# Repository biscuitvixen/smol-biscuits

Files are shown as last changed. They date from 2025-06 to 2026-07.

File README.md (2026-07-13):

# 🍪 Smol Biscuits SlimeVR Trackers






My own SlimeVR-compatible trackers, built because I wanted something
smaller. Like butterflies but before they were out! Custom PCB on a
Seeed Studio XIAO nRF52840, custom firmware fork, and a two-piece 3D
printed case with a flexible link between the battery and PCB sections.
They fit great and I love them!

## Table of Contents

- [Hardware](#hardware)
- [3D Printed Case](#3d-printed-case)
- [Firmware](#firmware)
- [Assembly](#assembly)
- [Setup & Calibration](#setup--calibration)

## Hardware

### PCB

Designed in KiCad, files in [`pcb/`](./pcb). A minimal carrier board for
the XIAO nRF52840, with sensors mounted on the opposite side.

### Sensors

| Component | Model | Function |
|---|---|---|
| IMU | ICM-45686 | 6-axis motion sensing |
| Magnetometer | QMC-6309 | Magnetic field detection |

### Battery

The board takes a LiPo. The included case is sized around a 150mAh cell -
go bigger if your case design has room for it.

## 3D Printed Case

Two-piece design: separate battery and PCB compartments connected by a
flexible TPU link. The joint lets the tracker bend naturally against your
body, which makes a real difference for all-day wear.

Print the flex link in TPU. Base plates should be PETG - they take real
strain from the strap and PLA will eventually fail on you. The top cover
and switch piece can be PLA or PETG, whichever you have to hand.

## Firmware

Firmware lives in [`firmware/`](./firmware) as a git submodule - a fork of
the SlimeVR firmware with specific support for this PCB.

Pre-compiled firmware is available in the [releases section](../../releases).

### Building from source

1. Clone with submodules:
   ```bash
   git clone --recurse-submodules https://github.com/biscuitvixen/smol-biscuits.git
   ```

2. Follow the [SlimeVR compilation guide](https://docs.slimevr.dev/smol-slimes/firmware/smol-compiling-firmware.html),
   then build with:
   ```bash
   west build -p auto -b xiao_ble -d build . -- -DNCS_TOOLCHAIN_VERSION=NONE -DBOARD_ROOT=.
   ```

## Assembly

### Soldering

The components on this board are small. Take your time.

1. Solder the sensor components onto the PCB. Leave the XIAO for now.
2. Pre-tin the battery terminals on the XIAO and the matching footprint
   on the PCB.
3. Use the solder jig to position the XIAO with battery terminals facing up.
4. Apply flux, place the sensor PCB on top aligning the battery terminals,
   and heat through the square pass-through pads while pressing the boards
   flat. Let it cool fully before moving it.
5. Inspect all joints and check for shorts with a multimeter before
   continuing.
6. Solder the castellated pins around the PCB edge, then solder the battery
   to the back of the sensor board.

### Programming

**Tracker:**

1. Connect via USB-C and double-tap the reset button. The device should
   appear as `XIAO-SENSE`.
2. Copy `update-slimenrf_xiao_sense_bootloader-0.9.2-SlimeVR.7_nosd.uf2`
   to the drive. It will remount as `SLIMENRF_XIAO_SENSE`.
3. Copy `firmware_tracker.uf2` to the drive. The tracker reboots
   automatically.

**Receiver:**

The Holyiot receiver is programmed via Nordic nRF Connect Programmer - flash
`firmware_receiver.hex`. For other hardware, follow the
[SlimeVR receiver docs](https://docs.slimevr.dev).

### Case assembly

1. Slide both bases onto a 30mm strap with the notches facing each other.
2. Place the flex link between the bases in its slot.
3. Insert the battery spacer, then lay the battery on top.
4. Hold the battery in place by its wires and snap the battery base down.
5. Place the PCB into the PCB base, aligning the switch with the cutout.
6. Slide the switch slider over the PCB switch.
7. Snap the top cover into place and adjust the strap to fit.

## Setup & Calibration

Follow the [SlimeVR pairing and calibration guide](https://docs.slimevr.dev/smol-slimes/firmware/smol-pairing-and-calibration.html).

## License

### Hardware

PCB files, 3D models, schematics, and case designs are licensed under
[CC BY-NC-SA 4.0](LICENSE-CC-BY-NC-SA). Personal and educational use is
free - just credit me and share improvements under the same terms.
Commercial use requires a separate arrangement; get in touch at
onlybiscuit7@gmail.com.

### Firmware

Firmware retains the original SlimeVR license terms:
[MIT](LICENSE-MIT) | [Apache 2.0](LICENSE-APACHE). See the firmware
submodule for the full details.

## Contributing

Pull requests and issues welcome.

## Support

- [SlimeVR Documentation](https://docs.slimevr.dev)
- SlimeVR Discord
- GitHub Issues

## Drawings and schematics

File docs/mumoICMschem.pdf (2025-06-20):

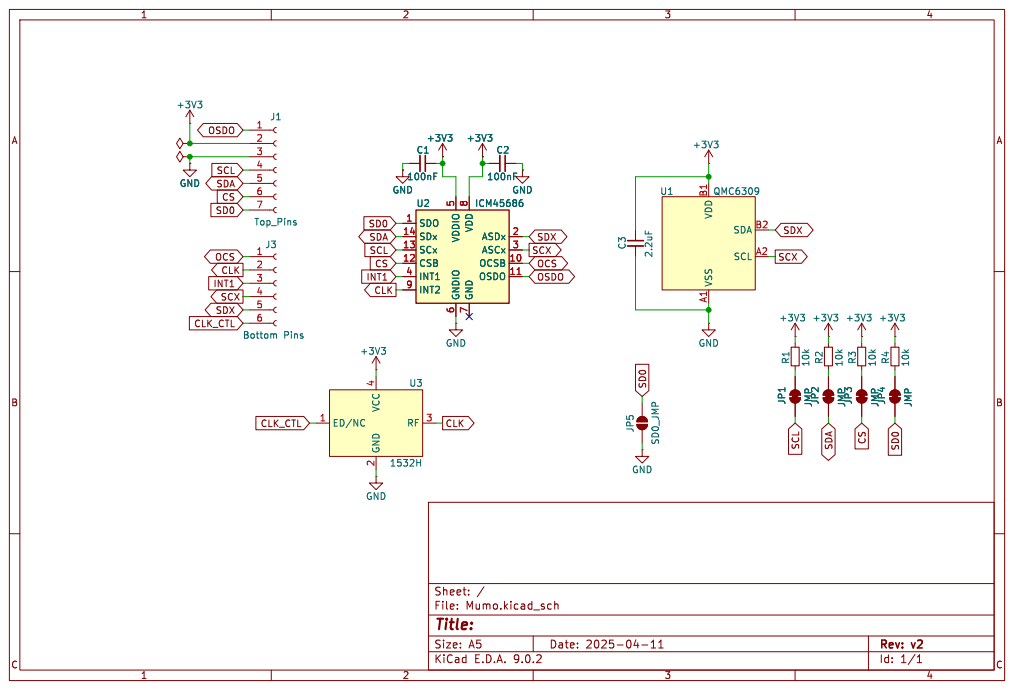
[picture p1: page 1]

7 ASDx 2 ASCx 3 OCSB 10 OSDO 11 U2 ICM45686 +3V3 GND VDD B1 VSS A1 SDA B2 SCL A2 U1 QMC6309 R3 10k +3V3 SCX CS

7 ASDx 2 ASCx 3 OCSB 10 OSDO 11 JP4 JP1 JMP JP2 JMP JP3 JMP JMP

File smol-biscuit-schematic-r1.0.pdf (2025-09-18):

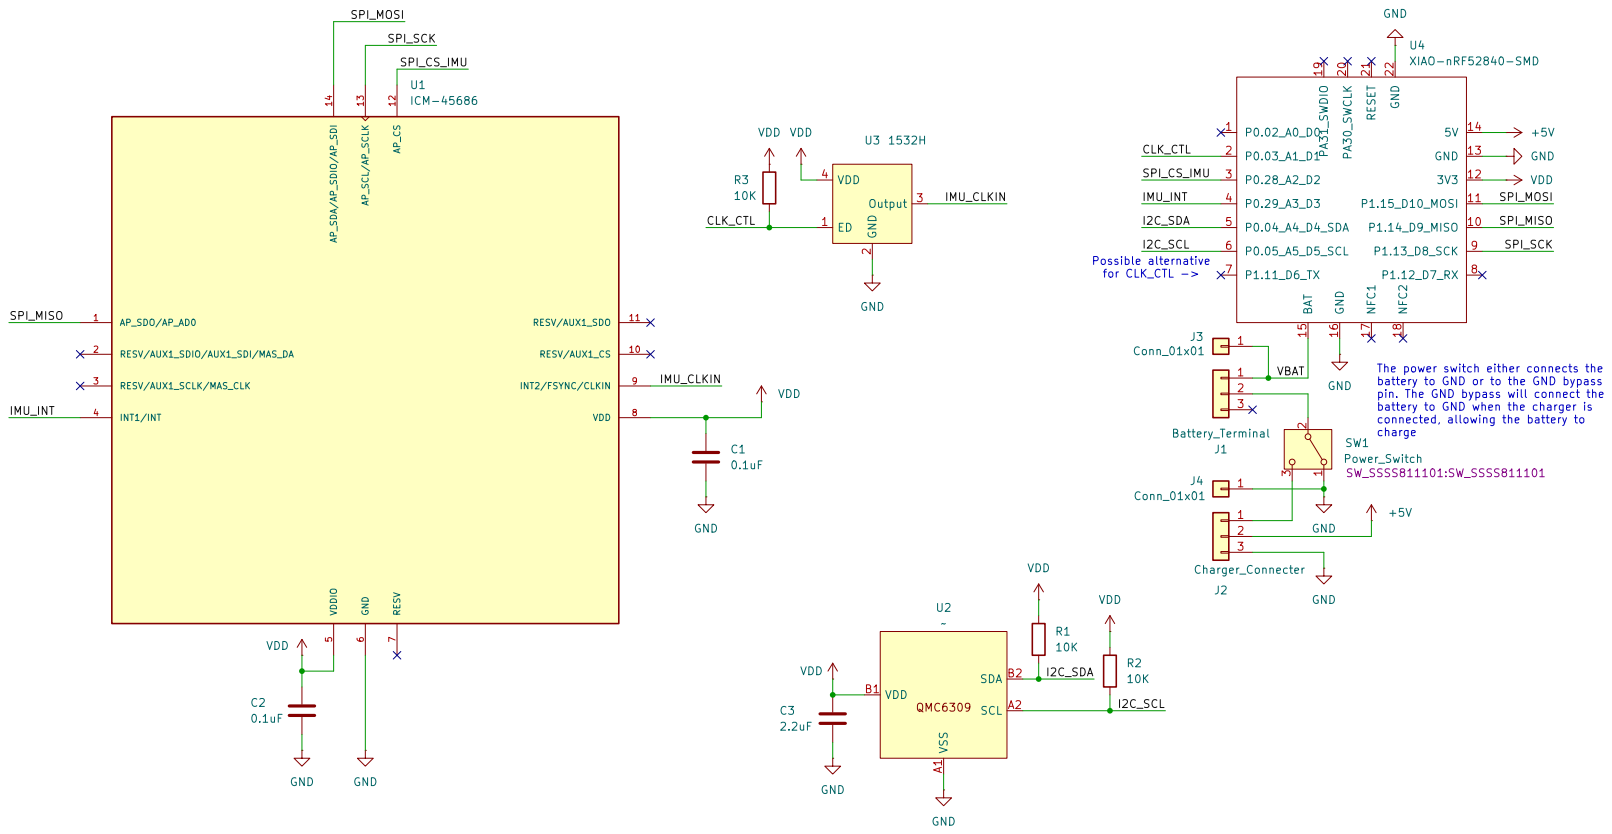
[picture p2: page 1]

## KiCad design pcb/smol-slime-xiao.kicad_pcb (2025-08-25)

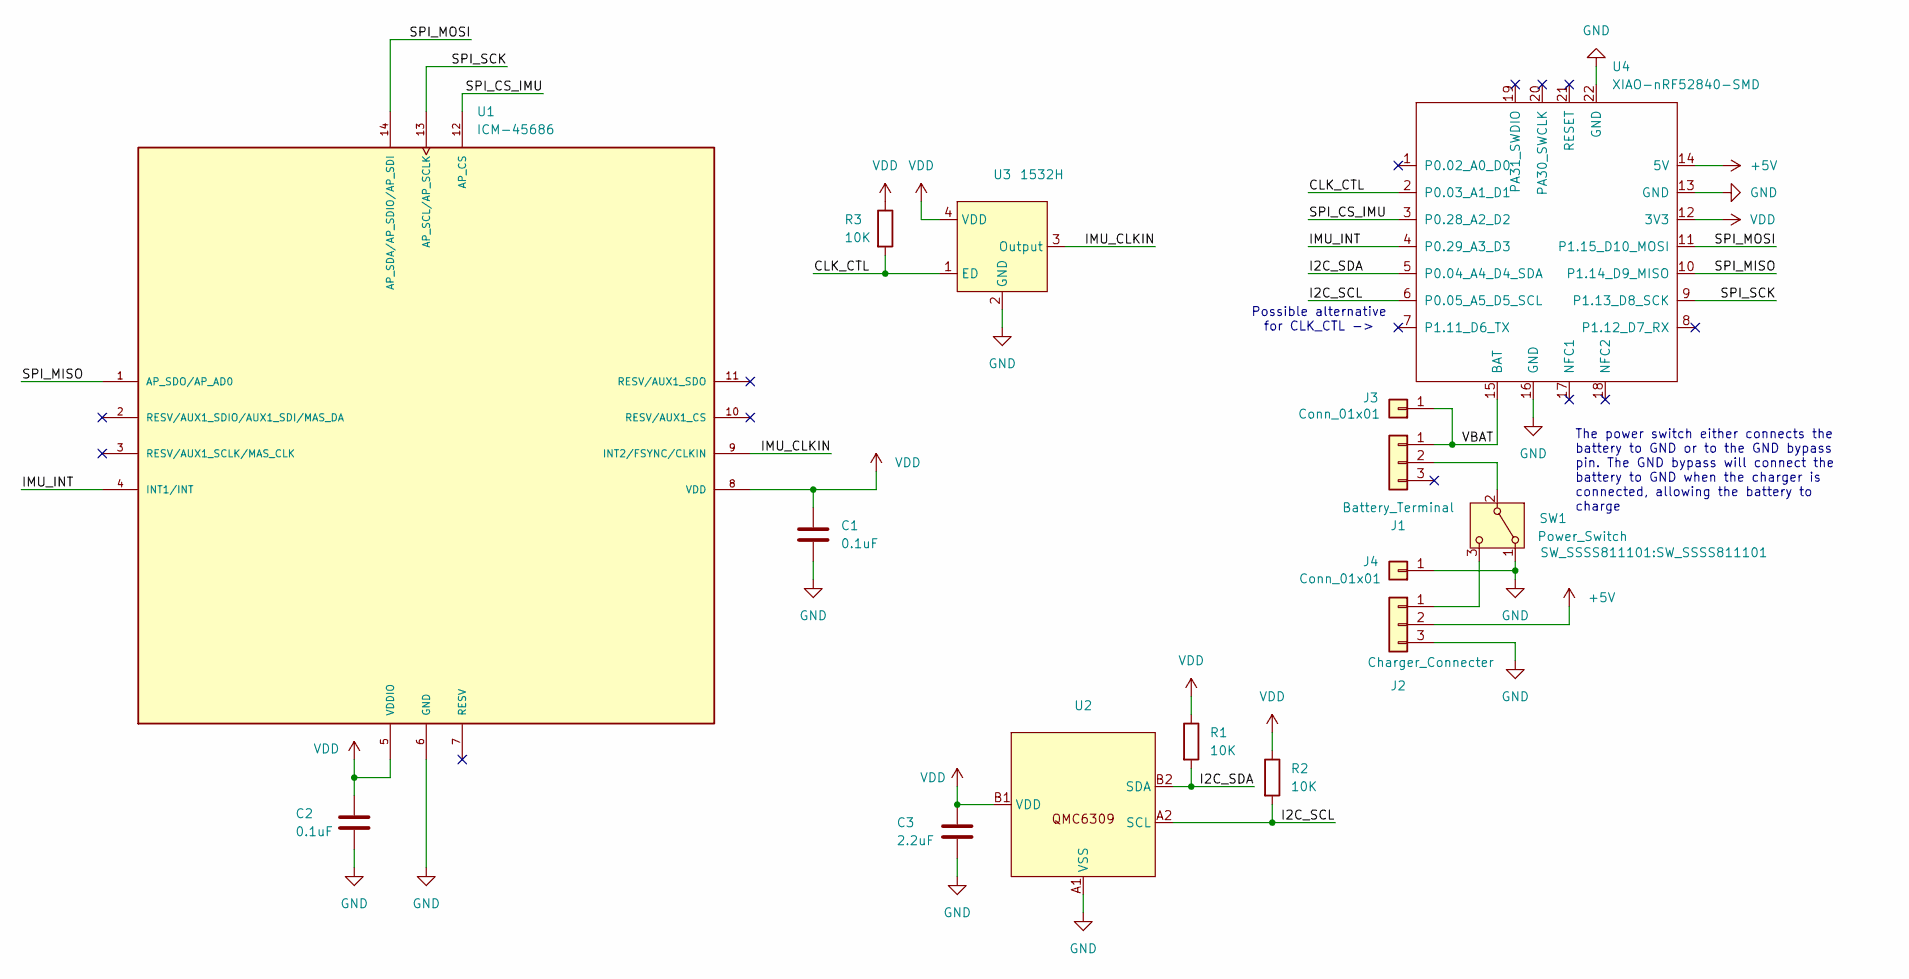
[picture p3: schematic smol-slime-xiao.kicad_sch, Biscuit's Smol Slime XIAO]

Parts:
C1, C2: 0.1uF; C_0603_1608Metric; LCSC PN C1591
C3: 2.2uF; C_0603_1608Metric; LCSC PN C100082
J1: Battery_Terminal; JST_PH2_SMT; LCSC PN C295747
J2: Charger_Connecter; PinPads_1x03_P2.54mm
J3, J4: Conn_01x01; Heat_Pad_1.0x1.0mm
R1, R2, R3: 10K; R_0603_1608Metric; LCSC PN C15401
SW1: Power_Switch; SW_SSSS811101; LCSC PN C109335
U1: ICM-45686; IC_ICM-45686; PARTREV 0.2; LCSC PN C22459454
U2: QMC6309; LCSC PN C5439871
U3: 1532H; Crystal_SMD_3225-4Pin_3.2x2.5mm_Silkscreenfix; LCSC PN C252344
U4: XIAO-nRF52840-SMD; XIAO-nRF52840-SMD-FixedSilkscreen

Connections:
+5V: J2.2, U4.14 (5V)
/CLK_CTL: R3.2, U3.1 (ED), U4.2 (P0.03_A1_D1)
/I2C_SCL: R2.2, U2.A2 (SCL), U4.6 (P0.05_A5_D5_SCL)
/I2C_SDA: R1.2, U2.B2 (SDA), U4.5 (P0.04_A4_D4_SDA)
/IMU_CLKIN: U1.9 (INT2/FSYNC/CLKIN), U3.3 (Output)
/IMU_INT: U1.4 (INT1/INT), U4.4 (P0.29_A3_D3)
/SPI_CS_IMU: U1.12 (AP_CS), U4.3 (P0.28_A2_D2)
/SPI_MISO: U1.1 (AP_SDO/AP_AD0), U4.10 (P1.14_D9_MISO)
/SPI_MOSI: U1.14 (AP_SDA/AP_SDIO/AP_SDI), U4.11 (P1.15_D10_MOSI)
/SPI_SCK: U1.13 (AP_SCL/AP_SCLK), U4.9 (P1.13_D8_SCK)
/VBAT: J1.1, J3.1, U4.15 (BAT)
GND: C1.1, C2.1, C3.1, J2.3, J4.1, SW1.1 (A), U1.6 (GND), U2.A1 (VSS), U3.2 (GND), U4.13 (GND), U4.16 (GND), U4.22 (GND)
unnamed: J1.2, SW1.2 (B)
unnamed: J2.1, SW1.3 (C)
VDD: C1.2, C2.2, C3.2, R1.1, R2.1, R3.1, U1.5 (VDDIO), U1.8 (VDD), U2.B1 (VDD), U3.4 (VDD), U4.12 (3V3)

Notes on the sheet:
The power switch either connects the battery to GND or to the GND bypass pin. The GND bypass will connect the battery to GND when the charger is connected, allowing the battery to charge
Possible alternative for CLK_CTL ->

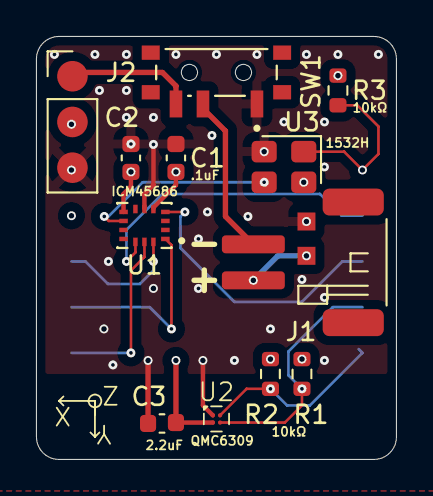
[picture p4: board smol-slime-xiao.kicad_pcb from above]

Board: 4 copper layers, 20.0 x 23.5 mm, 17 parts (1 on the bottom side), 15 nets.

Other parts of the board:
LogoCalligraphy: LOGO
LogoHead: LOGO

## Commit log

2025-06-17 Create empty project base
    [smol-slime-xiao.kicad_pcb, smol-slime-xiao.kicad_sch]
2025-06-18 Import ICM_45686 symbol
    [smol-slime-xiao.kicad_sch]
2025-06-18 Ignore kicad backups
2025-06-18 Convert footprint for KiCad 9 and add library
    [smol-slime-xiao.kicad_pcb]
2025-06-18 Add 3d model for ICM_45656
    [smol-slime-xiao.kicad_pcb]
2025-06-19 Add QMC6309 symbol and footprint
    [smol-slime-xiao.kicad_pcb, smol-slime-xiao.kicad_sch]
2025-06-19 Add schematic symbol for crystal
2025-06-20 Add 1532H4 oscillator
    [smol-slime-xiao.kicad_sch]
2025-06-20 Add capacitors
    [smol-slime-xiao.kicad_pcb, smol-slime-xiao.kicad_sch]
2025-06-21 Update design
    [smol-slime-xiao.kicad_sch]
2025-06-23 Added GND and VDD reference for Magnetometer
    [smol-slime-xiao.kicad_sch]
2025-07-02 Add Seeed OPL KiCad library as submodule
2025-07-02 Import XIAO footprint library
2025-07-03 Add XIAO MCU symbol
    [smol-slime-xiao.kicad_pcb, smol-slime-xiao.kicad_sch]
2025-07-03 Add IMU net labels
    [smol-slime-xiao.kicad_sch]
2025-07-03 Add net labels for QMC6309
    [smol-slime-xiao.kicad_sch]
2025-07-03 Added net labels to 1532H Oscillator
    [smol-slime-xiao.kicad_sch]
2025-07-03 Neaten QMC6309 wiring
    [smol-slime-xiao.kicad_sch]
2025-07-03 Neaten IMU wiring
    [smol-slime-xiao.kicad_sch]
2025-07-03 Add SPI connections to MCU
    [smol-slime-xiao.kicad_sch]
2025-07-03 Add I2C connections to MCU
    [smol-slime-xiao.kicad_sch]
2025-07-03 Add oscillator connections to MCU
    [smol-slime-xiao.kicad_sch]
2025-07-03 Fix label formatting
    [smol-slime-xiao.kicad_sch]
2025-07-03 Add pin assignments for MCU
    [smol-slime-xiao.kicad_sch]
2025-07-03 Add pull-up to ED for oscillator
    [smol-slime-xiao.kicad_sch]
2025-07-03 Rearrange for neatness
    [smol-slime-xiao.kicad_sch]
2025-07-03 Update components
    [smol-slime-xiao.kicad_pcb]
2025-07-04 Roughly lay out components
    [smol-slime-xiao.kicad_pcb]
2025-07-04 Re-arrange for optimal magnetometer placement
    [smol-slime-xiao.kicad_pcb]
2025-07-04 Add MCU connectors
    [smol-slime-xiao.kicad_sch]
2025-07-04 Fix edge cuts
    [smol-slime-xiao.kicad_pcb, smol-slime-xiao.kicad_sch]
2025-07-04 Rework board shape and arrangement
    [smol-slime-xiao.kicad_pcb]
2025-07-16 Add JLCPCB design rules for board validation
2025-07-16 Homogenise connector terminals
    [smol-slime-xiao.kicad_sch]
2025-07-16 Create 2.54mm pad footprint
2025-07-16 Add pad to power connector
    [smol-slime-xiao.kicad_sch]
2025-07-16 Update edge-cuts for board
    [smol-slime-xiao.kicad_pcb]
2025-07-17 Added power pads to board
    [smol-slime-xiao.kicad_pcb]
2025-07-17 Add battery JST connector
    [smol-slime-xiao.kicad_pcb, smol-slime-xiao.kicad_sch]
2025-07-17 Add descriptions to silkscreen
    [smol-slime-xiao.kicad_pcb]
2025-07-17 Update pin pad footprint
    [smol-slime-xiao.kicad_pcb]
2025-07-17 Revert silkscreen verbosity
    [smol-slime-xiao.kicad_pcb]
2025-07-18 Changed JST to SMT
    [smol-slime-xiao.kicad_pcb, smol-slime-xiao.kicad_sch]
2025-07-18 Add pours
    [smol-slime-xiao.kicad_pcb]
2025-07-18 Add descriptors
    [smol-slime-xiao.kicad_pcb]
2025-07-18 Move CLK_CTL to alternate GPIO
    [smol-slime-xiao.kicad_pcb, smol-slime-xiao.kicad_sch]
2025-07-18 Fix XIAO silkscreen overlap
    [smol-slime-xiao.kicad_pcb, smol-slime-xiao.kicad_sch]
2025-07-18 Fix default pad clearance on QMC6309 footprint
    [smol-slime-xiao.kicad_pcb]
2025-07-18 Connect QMC
    [smol-slime-xiao.kicad_pcb]
2025-07-18 Fix keep out zone
    [smol-slime-xiao.kicad_pcb]
2025-07-18 Fix QMC silkscreen clearance
    [smol-slime-xiao.kicad_pcb]
2025-07-18 Add JST vias
    [smol-slime-xiao.kicad_pcb]
2025-07-18 Fix C2 GND connection
    [smol-slime-xiao.kicad_sch]
2025-07-22 PCB Current
    [smol-slime-xiao.kicad_pcb]
2025-07-22 Add power switch
    [smol-slime-xiao.kicad_sch]
2025-07-23 Create VBAT_GND net for charge connector bypass
    [smol-slime-xiao.kicad_sch]
2025-07-23 Create 3 pad connector
2025-07-23 Changed charge connector footprint to 3 pin variant
    [smol-slime-xiao.kicad_pcb, smol-slime-xiao.kicad_sch]
2025-07-25 Update switch symbol and circuit logic to avail parts
    [smol-slime-xiao.kicad_sch]
2025-07-29 Reorganise PCB
    [smol-slime-xiao.kicad_pcb]
2025-07-29 Tied ground vias
    [smol-slime-xiao.kicad_pcb, smol-slime-xiao.kicad_sch]
2025-07-29 Balance VDD plane GND via cutoffs
    [smol-slime-xiao.kicad_pcb]
2025-07-29 Fix DRC errors
    [smol-slime-xiao.kicad_pcb]
2025-08-03 Add part numbers and datasheets for BOM
    [smol-slime-xiao.kicad_pcb, smol-slime-xiao.kicad_sch]
2025-08-03 Fix mis-wired oscillator
    [smol-slime-xiao.kicad_pcb, smol-slime-xiao.kicad_sch]
2025-08-03 Add logo, details and dedication
    [smol-slime-xiao.kicad_pcb]
2025-08-03 Fix footprint mismatch
    [smol-slime-xiao.kicad_pcb, smol-slime-xiao.kicad_sch]
2025-08-03 Correct part number field name
    [smol-slime-xiao.kicad_pcb, smol-slime-xiao.kicad_sch]
2025-08-03 Generate fabrication gerbers and drill files
    [smol-slime-xiao-B_Cu.gbl, smol-slime-xiao-B_Mask.gbs, smol-slime-xiao-B_Paste.gbp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]
2025-08-03 Generate BOM and Placement and move gerbers into production dir
    [smol-slime-xiao-B_Cu.gbl, smol-slime-xiao-B_Mask.gbs, smol-slime-xiao-B_Paste.gbp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]
2025-08-03 Update oscillator part
    [smol-slime-xiao.kicad_pcb, smol-slime-xiao.kicad_sch]
2025-08-03 Update fro production
    [smol-slime-xiao.kicad_pcb, smol-slime-xiao.kicad_sch]
2025-08-25 Update attribution
    [smol-slime-xiao.kicad_pcb]
2025-08-25 Fix missing reference designators
    [smol-slime-xiao.kicad_pcb]
2025-08-25 Update fabrication files for release
    [smol-slime-xiao-B_Cu.gbl, smol-slime-xiao-B_Mask.gbs, smol-slime-xiao-B_Paste.gbp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]
2025-08-25 Fix fab path
    [smol-slime-xiao-B_Cu.gbl, smol-slime-xiao-B_Mask.gbs, smol-slime-xiao-B_Paste.gbp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]
2025-09-18 Add schematic pdf
2025-10-27 Update README with firmware compilation and assembly instructions
2025-10-27 Revise README to enhance clarity and detail on features, assembly, and licensing for Smol Biscuits SlimeVR Trackers
2026-07-13 Revise README for improved clarity and detail on features, assembly, and licensing of Smol Biscuits SlimeVR Trackers
